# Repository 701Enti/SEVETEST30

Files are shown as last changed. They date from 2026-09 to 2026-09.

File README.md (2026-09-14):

# 简介

- 具有 16\*32RGB 显示阵列和大量环境传感器的物联网 AI 个性化时钟
- 基于 ESP32S3 模组和 ESP-IDF 框架开发
- 仅 TYPE-C 接入即可实现充电和程序调试(支持接口静电保护)
- 使用具有长边 32 灯\*短边 16 灯,共计 512 个 RGB灯珠的灯板 + 驱动板组成的显示模块
- 灯板和主控板采用易插拔的排线设计
- 板载电池和充电管理
- 支持电池电量计量
- 只需连接网络即可获取设备粗略位置并同步天气数据
- 最高支持 24bit 高保真音频播放/录制(DAC 最高支持 192kHz,ADC 最高支持 96kHz)
- 具有 3W 双声道音频功率放大器
- 喇叭接口采用易插拔端子设计
- 提供耳机输出
- 软件音量调节并支持蓝牙控制
- 环境光传感
- 板载麦克风阵列
- 姿态传感
- 地磁传感
- 线性振动马达
- 软关机低功耗设计
- NTP 网络时间同步
- TVOC 空气质量传感
- 温湿度传感
- 支持语音识别 ASR
- 支持语音合成 TTS
- 任意主流AI大语音模型API对话支持
- 通过物联工具实现个性化定制(等待开发和优化中)
- 交互式开关机(等待开发和优化中)

# 软件

- 业务代码编程语言为 C 语言
- 使用了 CMake 构建
- 基于 ESP-IDF 框架开发
- 本项目 IDE 开发环境推荐使用 Visual Studio Code / TRAE

# 软件安全设施

## .gitignore 敏感文件排除

- **SDK 配置文件 - sdkconfig**

  - SEVETEST30 的 WIFI 连接密码和 API 相关密钥均需要在 SDK 配置编辑器(menuconfig)设置,其生成的 sdkconfig 硬编码这些敏感内容
  - 提供安全的默认无密钥初始配置文件 sdkconfig.defaults

- **其他常见敏感文件**:
  - 环境变量和其他配置文件（含 API 密钥/数据库密码）
  - 加密密钥和证书文件（SSL/SSH 私钥）
  - 云服务凭证文件（AWS/GCP 访问密钥）
  - 数据库文件和备份（可能含敏感数据）
  - 日志文件（可能泄露调试信息）
  - 开发工具配置文件（含私有仓库令牌）
  - 网络连接配置文件（VPN/RDP 凭证）

## 关键分支的 PR 检查(基于 TruffleHog)

- **相关技术实现**:

  - 当 SEVETEST30 仓库的关键分支有新的 pull&request 时,必须经过 Github 工作流检查才可以进行 pull&request(需要仓库设置规则)
  - 工作流中使用 TruffleHog 检查整个提交历史是否含敏感内容
  - 也可以手动触发来人工检查结果

- **相关工作流**:
  - .github/workflows/TruffleHogPRCheck.yml

# 硬件

- **控制板 - SEVETEST30 核心控制板(50mm \* 100mm)**:

  - (目前硬件调试中,以下芯片使用仅供参考,很可能随时终止或更换某些器件的使用,请勿用于现实业务,修改恕不通知,建议等待正式版发布)[^4]
  - (由于硬件更改的可能,硬件工程文件尚不公开分发,我们可能在正式版发布时正式发布相关硬件文件)
  - MCU 模组:ESP32-S3-WROOM-1(N16R8 版本)
  - 字库:GT32L32S0140
  - 音频编解码:ES8388
  - 音频功率放大器:NS4268
  - 数字电位器(音量调节):TPL0401B
  - IO 扩展器:TCA6416A
  - 环境光传感器:OPT3001
  - 麦克风阵列:ZTS6156
  - 姿态传感器:LSM6DS3TRC
  - 地磁传感器:HSCDTD008A
  - 线性振动马达
  - 线性振动马达驱动器:BD6210F-E2
  - 离线 RTC:BL5372
  - TVOC 空气质量传感器:AGS10
  - 温湿度传感器:AHT21
  - DC-DC 电池充放电管理:SLM6300
  - 电池电量计量:MAX17048G+T10
  - USB 接口保护:UBT26A05L03
  - 电池(3.7V) -> 辅助电源(5V) DC-DC 升压芯片:TPS61230ARNSR
  - 数字电位器(辅助电源电压下调):TPL0401A
  - 辅助电源(5V) -> 主电源(3.3V) LDO 降压芯片:CJT1117B-3.3
  - 主电源(3.3V) -> AGS10 供电(3v) LDO 降压芯片:H7130-1

- **显示板 - SEVETEST30 灯板(50mm \* 100mm)**:

  - 普通共阳RGB灯珠

- **显示驱动板 - SEVETEST30 显示驱动板(50mm \* 100mm)**:

  - ICND2013
  - ICND2038S

- **必要设备 I2C 硬件通信地址**:

  - ES8388 (音频编解码) - 10
  - TPL0401B(音量调整) - 3E
  - TPL0401A(5V 电压下调) - 2E
  - TCA6416A(IO 扩展) - 20
  - MAX17048(电量计量) - 36

- **自举设备 I2C 硬件通信地址**:

  - AHT21(温湿度传感) - 38
  - AGS10(空气质量传感) - 1A
  - OPT3001(环境光传感) - 44
  - LSM6DS3TR-C(姿态传感) - 6A
  - HSCDTD008A(地磁传感) - 0C

# 硬件安全设施

## 接口保护

- **USB 接口**:
  - 支持静电保护,通过 UBT26A05L03
  - 支持浪涌保护,通过 UBT26A05L03

# 文档相关

## 在 Github 上的 SEVETEST30 文档仓库

- **仓库链接**: https://github.com/701Enti/DOC-SEVETEST30
- **文档撰写方式**: Doxygen 根据代码和注释生成
- **特别声明**:
  - SEVETEST30 文档仓库不是私有仓库,您完全可以 push 个人分支生成的文档到独立分支,甚至可以是您对 SEVETEST30 的见解等其他任何与 SEVETEST30 相关的内容,只要您没有影响自动文档或进行不合理的推送
  - 为保证资源充足,只会为关键分支提供自动文档生成,具体会触发工作流的关键分支在工作流文件 DoxygenAutoDocSync.yml 中可设置和查看
  - 当然,如果您希望自己的分支像关键分支一样可云端部署文档,您可以在本地运行 Doxygen 生成文档,并推送到 SEVETEST30 文档仓库与个人分支同名的分支,之后可联系 SEVETEST30 团队协商,他们管理文档的云端部署
- **文档修改**:
  - 更改 SEVETEST30 仓库的源码和注释内容即可,因为生成就是根据这些完成的,代码即文档
  - 由于生成结果文件非常多,不适合编辑修改管理工作,并且生成后的推送会覆盖之前的所有内容,更改源码注释反而更可靠,因此,目前不考虑生成后文件内容再修改的工作,即使是发布分支
- **相关技术实现**:
  - 当 SEVETEST30 仓库的关键分支有新的 push/pull&request 时(或者手动触发),自动在 Github 工作流中使用 Doxygen 生成文档,并提交新文档到文档仓库的同名分支
  - 例如 SEVETEST30 名为 A 分支的推送,将触发文档仓库名为 A 分支的更新
  - 文档生成和推送工作使用可复用工作流: https://github.com/701Enti/Github-WorkFlows/blob/master/.github/workflows/doxygen-auto-code-to-doc.yml (它存储在 701Enti 的专门工作流文件存储库)
  - 为保证资源充足,只会为关键分支提供自动文档生成,具体会触发工作流的关键分支在工作流文件 DoxygenAutoDocSync.yml 中可设置和查看
- **全流程案例**:
  - 以下是通过 Doxygen 自动生成官方文档的相关工作全流程(仅针对关键分支,如分支 A)
  - SEVETEST30 仓库关键分支 A 的 push
  - -> DoxygenAutoDocSync 触发
  - -> DoxygenAutoDocSync 调用 doxygen-auto-code-to-doc
  - -> doxygen-auto-code-to-doc 触发,根据 A 分支代码生成文档并将更改推送到文档仓库的 A 分支
  - (doxygen-auto-code-to-doc 结束)
  - -> DoxygenAutoDocSync 调用 OfficialDocSubmoduleSync
  - -> OfficialDocSubmoduleSync 触发,更新子模块,将更改推送到 A 分支的机器人分支并发起该分支到 A 分支的 PR
  - (OfficialDocSubmoduleSync 结束)
  - (DoxygenAutoDocSync 结束)
  - -> PR 审查 -> 完成
  - [注意: SEVETEST30 仓库是将每个文档仓库作为子模块独立管理的,子模块名必须与文档仓库名一致]
- **相关工作流**:
  - .github/workflows/DoxygenAutoDocSync.yml
  - .github/workflows/OfficialDocSubmoduleSync.yml
  - https://github.com/701Enti/Github-WorkFlows/blob/master/.github/workflows/doxygen-auto-code-to-doc.yml

# 第三方代码使用声明

## components/matrix_f64/matrix_fp64_mult_ansi.c

- **原项目**: esp-dsp
- **项目链接**: https://github.com/espressif/esp-dsp
- **原文件**: dspm_mult_f32_ansi.c
- **原文件协议类型**: Apache License 2.0
- **原文件 LICENSE 链接**: http://www.apache.org/licenses/LICENSE-2.0
- **修改说明**:
  - 类型为 float 的输入/输出参数被修改为 double 类型以提高运算精度[^1]
  - 函数名中的"\_f32"被删除,"dspm"或"dsps"改为"matrix_fp64"
  - 文件重命名：dspm_mult_f32_ansi.c → matrix_fp64_mult_ansi.c
  - 注释了原文件所有包含,仅包含接口头文件 matrix_fp64.h

## components/matrix_f64/matrix_fp64_sub_ansi.c

- **原项目**: esp-dsp
- **项目链接**: https://github.com/espressif/esp-dsp
- **原文件**: dsps_sub_f32_ansi.c
- **原文件协议类型**: Apache License 2.0
- **原文件 LICENSE 链接**: http://www.apache.org/licenses/LICENSE-2.0
- **修改说明**:
  - 类型为 float 的输入/输出参数被修改为 double 类型以提高运算精度[^1]
  - 函数名中的"\_f32"被删除,"dspm"或"dsps"改为"matrix_fp64"
  - 文件重命名：dsps_sub_f32_ansi.c → matrix_fp64_sub_ansi.c
  - 添加接口头文件 matrix_fp64.h 的包含

## components/matrix_f64/matrix_fp64_dotprod_ansi.c

- **原项目**: esp-dsp
- **项目链接**: https://github.com/espressif/esp-dsp
- **原文件**: dsps_dotprod_f32_ansi.c
- **原文件协议类型**: Apache License 2.0
- **原文件 LICENSE 链接**: http://www.apache.org/licenses/LICENSE-2.0
- **修改说明**:
  - 类型为 float 的输入/输出参数被修改为 double 类型以提高运算精度[^1]
  - 函数名中的"\_f32"被删除,"dspm"或"dsps"改为"matrix_fp64"
  - 文件重命名：dspm_sub_f32_ansi.c → matrix_fp64_dotprod_ansi.c
  - 注释了原文件所有包含,仅包含接口头文件 matrix_fp64.h

## sevetest30_board/board_def.h

- **原项目**: esp-adf
- **项目链接**: https://github.com/espressif/esp-adf
- **项目 LICENSE 链接**: https://github.com/espressif/esp-adf/blob/master/LICENSE
- **原文件**: board_def.h
- **原文件协议类型**: MIT
- **修改说明**:
  - 更改为项目需要的数值设置
  - 添加一些项目个性化需要的定义

## sevetest30_board/board_pins_config.c

- **原项目**: esp-adf
- **项目链接**: https://github.com/espressif/esp-adf
- **项目 LICENSE 链接**: https://github.com/espressif/esp-adf/blob/master/LICENSE
- **原文件**: board_pins_config.c
- **原文件协议类型**: MIT
- **修改说明**:
  - 更改为项目需要的数值设置

## sevetest30_board/board_pins_config.h

- **原项目**: esp-adf
- **项目链接**: https://github.com/espressif/esp-adf
- **项目 LICENSE 链接**: https://github.com/espressif/esp-adf/blob/master/LICENSE
- **原文件**: board_pins_config.h
- **原文件协议类型**: MIT
- **修改说明**:
  - 更改为项目需要的数值设置

## sevetest30_board/board.c

- **原项目**: esp-adf
- **项目链接**: https://github.com/espressif/esp-adf
- **项目 LICENSE 链接**: https://github.com/espressif/esp-adf/blob/master/LICENSE
- **原文件**: board.c
- **原文件协议类型**: MIT
- **修改说明**:
  - 更改为项目需要的数值设置

## sevetest30_board/board.h

- **原项目**: esp-adf
- **项目链接**: https://github.com/espressif/esp-adf
- **项目 LICENSE 链接**: https://github.com/espressif/esp-adf/blob/master/LICENSE
- **原文件**: board.h
- **原文件协议类型**: MIT
- **修改说明**:
  - 更改为项目需要的数值设置

## main/AGS10.c 和 main/include/AGS10.h 的 Calc_CRC8 函数

- **原文件**:来自奥松电子官方的 AGS10 数据手册内(需登录后点击"文件下载"获取手册) https://www.aosong.com/Products/info.aspx?lcid=&proid=49
- **原文件协议类型**: (未发现声明)
- **修改说明**:
  - 添加日志打印相关

## [^1]: 值得明确的是修改为 double 后,运算需要的时间可能延长

## [^4]: 本项目开发者和贡献者不承担任何硬件更改活动导致的财产损失,信息泄露和人员伤亡(详见下方 法律声明 - 免责声明)

# 法律声明 - 版权相关

1. 所有文件头部均已保留原始版权声明
2. 完整协议文本请通过附加的相关链接查看
3. 详细修改记录见各文件头部注释块
4. 为了明确第三方代码的原作者信息,相关内容及 API 帮助不在 SEVETEST30 文档中显示

# 法律声明 - 免责声明

- 本项目的开发者及贡献者（以下简称“我们”）不对任何因使用本项目（包括但不限于硬件修改、软件配置或数据使用）导致的直接或间接损失负责，包括但不限于：
- 硬件损坏、财产损失或人身伤害；
- 数据泄露、隐私问题或系统故障；
- 因违反法律法规或第三方权利导致的后果。
- 使用本项目即代表您同意自行承担所有风险。我们不提供任何明示或默示的担保，包括适销性、特定用途适用性或无侵权保证。
- 如需正式法律条款，请参阅项目许可证（LICENSE 文件）或单独的法律文件。

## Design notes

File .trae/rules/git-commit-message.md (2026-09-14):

---
alwaysApply: true
scene: git_message
---

在此处编写规则，自定义 AI 生成提交信息的风格。
中文提交信息

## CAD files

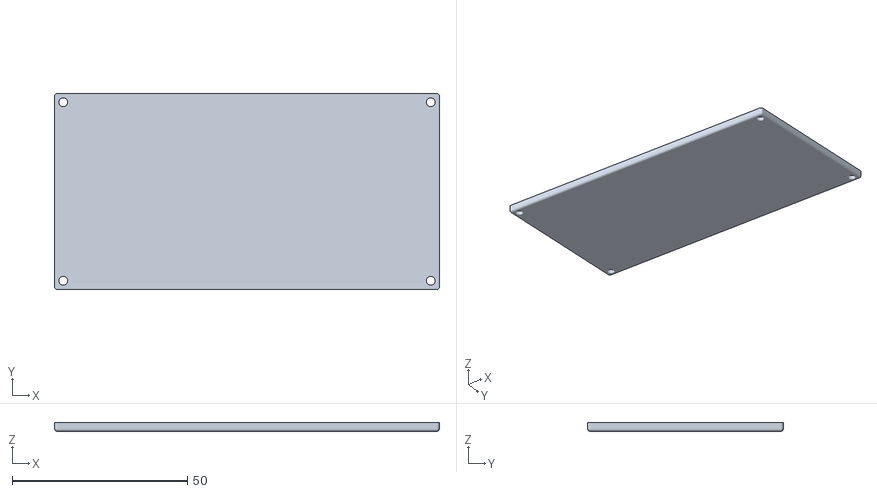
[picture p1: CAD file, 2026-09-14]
cad_case/export/stl/盖板.stl
110.0 x 56.0 x 2.50

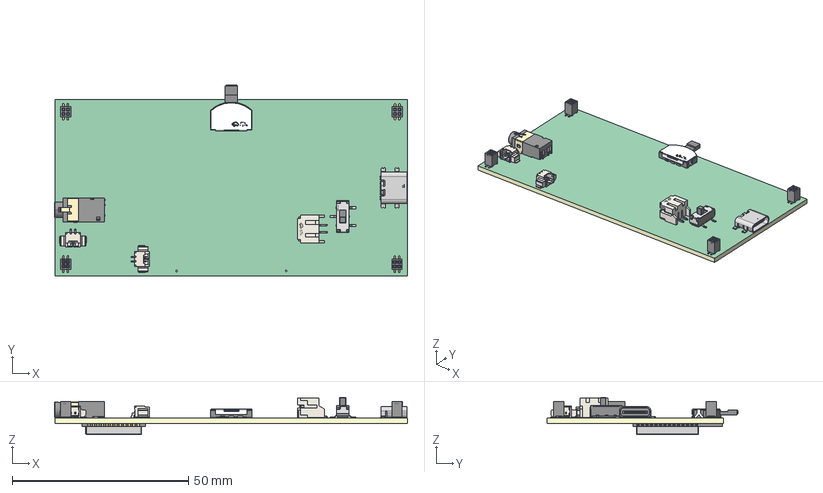
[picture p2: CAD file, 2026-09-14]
pcb/export/PT5/核心控制模块PT5_2026-08-22.step
100.1 x 54.1 x 10.5 mm
Board~6ucR
TopCopper~6ucR
BottomCopper~6ucR
TopSilkscreen~6ucR
BottomSilkscreen~6ucR
TopFpcStiffener~6ucR
BottomFpcStiffener~6ucR
HDR-SMD_ZX-PM1.27-2-2PU-W~HDR-SMD_ZX-PM1.27-2-2PU-W~6ucR x 4
CONN-SMD_2P-P2.00_XUNPU_WAFER-PH2.0-2PWB~CONN-SMD_2P-P2.00_XUNPU_ WAFER-PH2.0-2PWB~6ucR
CONN-SMD_532610271~CONN-SMD_532610271~6ucR x 2
SW-SMD_SHOUHAN_MST-22D18G23J_C2875122~SW-SMD_SHOUHAN_MST-22D18G23J_ C2875122~6ucR
USB-C-SMD_TYPEC-16PIN~USB-C-SMD_TYPEC-16PIN~6ucR
AUDIO-TH_ST-0337D00-071-1A2H~AUDIO-TH_ST-0337D00-071-1A2H~6ucR
SW-SMD_TM-2022-3~SW-SMD_TM-2022-3~6ucR
WIRELM-SMD_ESP32-S3-WROOM-1~WIRELM-SMD_ESP32-S3-WROOM-1~6ucR

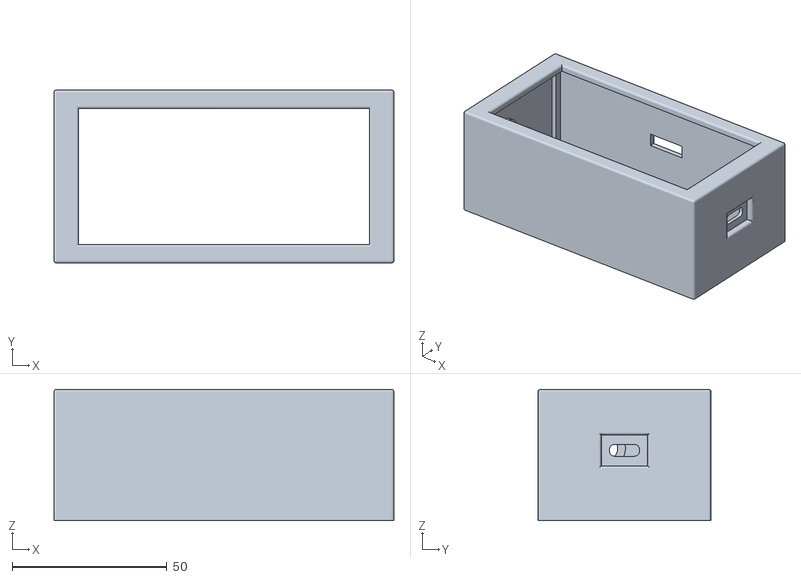
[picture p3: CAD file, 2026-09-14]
cad_case/export/stl/壳体.stl
110.0 x 56.0 x 42.5

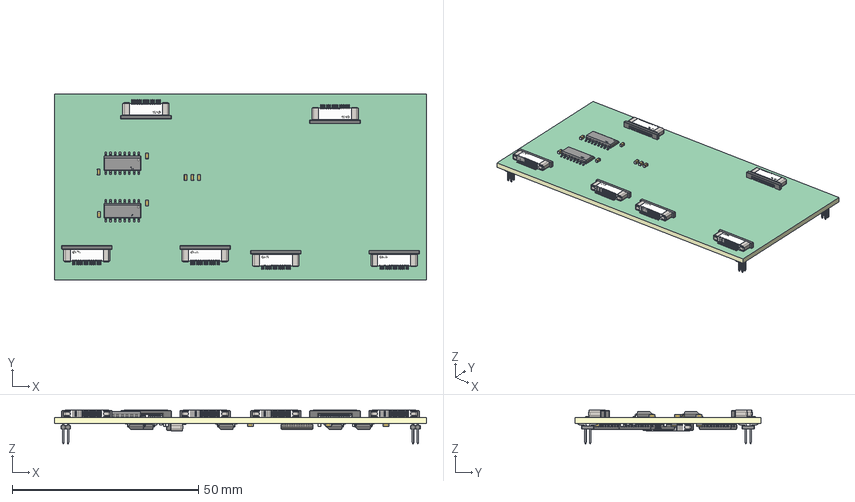
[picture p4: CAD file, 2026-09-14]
pcb/export/PT5/显示驱动模块_2026-08-22.step
100.0 x 50.0 x 9.10 mm
Board~aeRw
TopCopper~aeRw
BottomCopper~aeRw
TopSilkscreen~aeRw
BottomSilkscreen~aeRw
TopFpcStiffener~aeRw
BottomFpcStiffener~aeRw
HDR-SMD_4P-P1.27-V-M-R2-C2-LS5.3~HDR-SMD_4P-P1.27-V-M-R2-C2-LS5.3~aeRw x 4
R0603~R0603~aeRw x 12
C0603~C0603_L1.6-W0.8-H0.8~aeRw x 14
SOP-16_L9.9-W3.9-P1.27-LS6.0-BL~SOP-16_L9.9-W3.9-P1.27-LS6.0-BL~aeRw x 2
SSOP-24_L8.7-W3.9-P0.64-LS6.0-BL_1~SSOP-24_ L8.7-W3.9-P0.64-LS6.0-BL~aeRw x 6
FPC-SMD_P0.50-16P_LCS-SJ-H2.0~FPC-SMD_P0.50-16P_LCS-SJ-H2.0~aeRw x 7

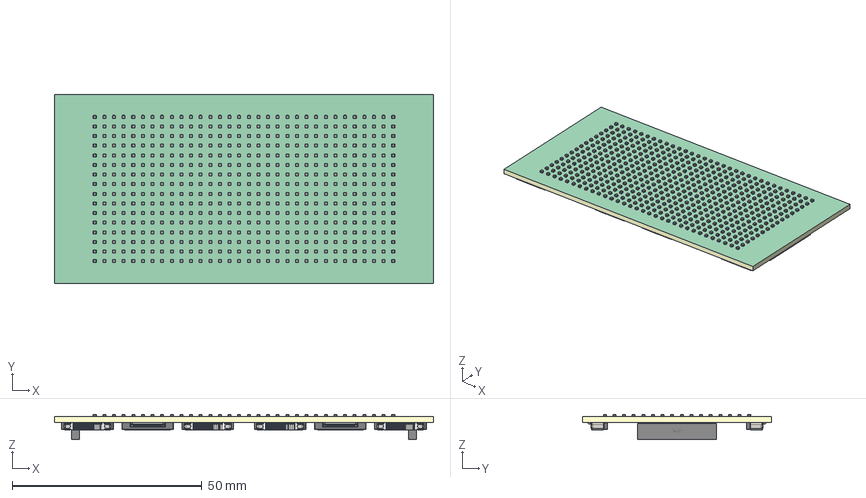
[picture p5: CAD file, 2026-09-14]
pcb/export/PT5/显示面板_2026-08-22.step
100.0 x 50.0 x 6.69 mm
Board~eJlu
TopCopper~eJlu
BottomCopper~eJlu
TopSilkscreen~eJlu
BottomSilkscreen~eJlu
TopFpcStiffener~eJlu
BottomFpcStiffener~eJlu
LED-ARRAY-SMD_4P-L0.80-W0.80-BR~LED-ARRAY-SMD_ 4P-L0.80-W0.80-H0.6-BR~eJlu x 512
FPC-SMD_P0.50-16P_LCS-SJ-H2.0~FPC-SMD_P0.50-16P_LCS-SJ-H2.0~eJlu x 6
HDR-SMD_16P-P1.27-V-F_X1311FVS-16-C43D35R2~HDR-SMD_16P-P1.27-V-F_ X1311FVS-16-C43D35R2~eJlu x 2

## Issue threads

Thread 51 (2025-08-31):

传感器校准generate_GS_calibration_static_model工作流程潜在问题修复

Zeng-Jinlin, 2025-08-31:
修复generate_GS_calibration_static_model工作流程潜在问题,可能保护数学库完善和修复:
我们使用椭球拟合算法完成对校准模型的构建
由于各种因素,传感器测得数据点分布近似一个x-y-z空间中的椭球
算出这个椭球相关参数,确定它,我们就可反过来推算实际值
然而,出现计算结果不合理,如参数小于0问题,这不正常,它不是椭球,因此我们需要修复bug

Zeng-Jinlin, 2025-08-31:
LU分解求逆是最小二乘法椭球拟合中关键一步,对于我们当前的方案选择来说

Zeng-Jinlin, 2025-08-31:
我们已经进行很多修复,并同时增加优化

Zeng-Jinlin, 2025-08-31:
但是实际校准工作测试发现椭球拟合结果还是存在负值,问题依旧
这使我开始怀疑硬件问题,尤其是当初不懂,layout时,把传感器设计在PCB中间位置
我会网购一个HSCDTD008A小板,外接到我们的主控板,以验证这个猜想

Closed 2025-10-01.

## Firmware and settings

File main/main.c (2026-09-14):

/*
 * 701Enti MIT License
 *
 * Copyright © 2024 <701Enti organization>
 *
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
 * THE SOFTWARE IS PROVIDED “AS IS”, WITHOUT WARRANTY OF ANY KIND, EXPRESS OR
 * IMPLIED, INCLUDING BUT NOT LIMITED TO THE WARRANTIES OF MERCHANTABILITY,
 * FITNESS FOR A PARTICULAR PURPOSE AND NONINFRINGEMENT. IN NO EVENT SHALL THE
 * AUTHORS OR COPYRIGHT HOLDERS BE LIABLE FOR ANY CLAIM, DAMAGES OR OTHER
 * LIABILITY, WHETHER IN AN ACTION OF CONTRACT, TORT OR OTHERWISE, ARISING FROM,
 * OUT OF OR IN CONNECTION WITH THE SOFTWARE OR THE USE OR OTHER DEALINGS IN THE
 * SOFTWARE.
 */

// 如您发现一些问题，请及时联系我们，我们非常感谢您的支持
// github: https://github.com/701Enti

#include <stdbool.h>
#include <stdint.h>
#include <stdio.h>
#include <string.h>

#include "esp_log.h"
#include "esp_peripherals.h"

#include "esp_sleep.h"
#include "esp_wifi.h"
#include "freertos/idf_additions.h"
#include "lwip/dns.h"
#include "nvs_flash.h"

#include "OPT3001.h"
#include "audio_hal.h"
#include "board_ctrl.h"
#include "board_def.h"
#include "board_pins_config.h"
#include "gt32l32s0140.h"

#include "HSCDTD008A.h"
#include "TCA6416A.h"
#include "calibration_tools.h"
#include "esp_timer.h"
#include "math_tools.h"
#include "sevetest30_BWEDA.h"
#include "sevetest30_IWEDA.h"
#include "sevetest30_LedArray.h"
#include "sevetest30_SWEDA.h"
#include "sevetest30_UI.h"
#include "sevetest30_config.h"
#include "sevetest30_gpio.h"
#include "sevetest30_sound.h"
#include "sevetest30_touch.h"

board_ctrl_t board_ctrl = {0};

char *system_json_head_prompt =
    "你是一个部署在SEVETEST30智能闹钟上的AI语音助手,"
    "你的名字是:07(零七,中文谐音寓意trying,数字取自701Enti),"
    "SEVETEST30是github上的701Enti组织归属的非盈利开源项目."
    "你可以和我聊天,简单的问题尽量用简短文字回答问题."
    "以下信息来自我的SEVETEST30闹钟通过网络API或硬件传感器获取的数据."
    "实时更新,我们的聊天可以不涉及."
    "注意:你需要根据时区获取当前时间,这里不会提供."
    "注意:位置数据来自IP定位,不要引起用户不必要的恐慌,经纬度数据可能不准确."
    "注意:用户通过语音识别聊天,文字书写可能错误,请重点关注拼音和上下文,"
    "忽略多音字歧义.";

void init(void);
void test(void);

esp_err_t AI_chat(void);

void app_main(void) {

  init();

  refresh_battery_data();
  refresh_env_temp_hum_data();
  refresh_env_TVOC_data(true);

  refresh_position_data();
  refresh_current_weather_data();

  if (xSemaphoreTake(update_ui_data_mutex, pdMS_TO_TICKS(100)) == pdTRUE) {
    clean_all_draw_buf();
    xSemaphoreGive(update_ui_data_mutex);
  }

  test();

  int UI_switch = 0;
  bool UI_changed = false;
  int64_t UI_changed_time = 0;

  while (1) {

    vTaskDelay(pdMS_TO_TICKS(10));

    refresh_systemtime_data();

    if (ext_io_ctrl.auto_read_INT) {
      if (ext_io_level_service() == ESP_OK) {
        ext_io_ctrl.auto_read_INT = false;

        if (board_ctrl.p_ext_io_value->thumbwheel_CW == 0 &&
            board_ctrl.p_ext_io_value->thumbwheel_CCW == 1) {
          if (board_ctrl.p_ext_io_value->DISABLE_LED_BOARD) {
            continue;
          }
          vibra_motor_start();
          vTaskDelay(pdMS_TO_TICKS(50));
          vibra_motor_stop();
          UI_switch++;
          UI_changed = true;
        } else if (board_ctrl.p_ext_io_value->thumbwheel_CW == 1 &&
                   board_ctrl.p_ext_io_value->thumbwheel_CCW == 0) {
          if (board_ctrl.p_ext_io_value->DISABLE_LED_BOARD) {
            continue;
          }
          vibra_motor_start();
          vTaskDelay(pdMS_TO_TICKS(50));
          vibra_motor_stop();
          UI_switch--;
          UI_changed = true;
        } else if (board_ctrl.p_ext_io_value->thumbwheel_CW == 0 &&
                   board_ctrl.p_ext_io_value->thumbwheel_CCW == 0) {

          vTaskDelay(pdMS_TO_TICKS(200));
          ext_io_level_service();

          if (!(board_ctrl.p_ext_io_value->thumbwheel_CW == 0 &&
                board_ctrl.p_ext_io_value->thumbwheel_CCW == 0)) {
            board_ctrl.p_ext_io_value->DISABLE_LED_BOARD =
                !(board_ctrl.p_ext_io_value->DISABLE_LED_BOARD);
            sevetest30_board_ctrl(&board_ctrl, BOARD_CTRL_EXT_IO);
            vibra_motor_start();
            vTaskDelay(pdMS_TO_TICKS(100));
            vibra_motor_stop();
            continue;
          }

          if (board_ctrl.p_ext_io_value->DISABLE_LED_BOARD) {
            continue;
          }

          if (xSemaphoreTake(update_ui_data_mutex, pdMS_TO_TICKS(100)) ==
              pdTRUE) {
            clean_all_draw_buf();
            facial_expression_show(1, 1, "normal");
            xSemaphoreGive(update_ui_data_mutex);
          }

          vibra_motor_start();
          vTaskDelay(pdMS_TO_TICKS(50));
          vibra_motor_stop();
          vTaskDelay(pdMS_TO_TICKS(100));
          vibra_motor_start();
          vTaskDelay(pdMS_TO_TICKS(50));
          vibra_motor_stop();

          int64_t start_time = esp_timer_get_time();
          while (board_ctrl.p_ext_io_value->thumbwheel_CW == 0 &&
                 board_ctrl.p_ext_io_value->thumbwheel_CCW == 0) {
            vTaskDelay(pdMS_TO_TICKS(100));
            ext_io_level_service();
            if (esp_timer_get_time() - start_time > 5 * 1000 * 1000) {
              vibra_motor_start();
              sevetest30_shutdown();
            }
          }

          esp_err_t ret = AI_chat();
          if (ret != ESP_OK) {
            ESP_LOGE("main", "AI_chat 失败,错误码：%d", ret);
            if (xSemaphoreTake(update_ui_data_mutex, pdMS_TO_TICKS(100)) ==
                pdTRUE) {
              clean_all_draw_buf();
              if (ret == ESP_ERR_INVALID_STATE) {
                show_wifi_not_connected(1, 1);
              } else if (ret == ESP_FAIL) {
                facial_expression_show(1, 1, "error");
              }
              xSemaphoreGive(update_ui_data_mutex);
              vTaskDelay(pdMS_TO_TICKS(1000));
            }
          }
          UI_changed = true;
        }
      }
    }

    if (xSemaphoreTake(update_ui_data_mutex, 100) == pdTRUE) {
      switch (UI_switch) {
      case -1: {
        if (UI_changed) {
          clean_all_draw_buf();
          memset(media_ctrl_roll_print_str, 0,
                 sizeof(media_ctrl_roll_print_str));
        }
        if (xSemaphoreTake(data_mutex_media_ctrl_roll_print, 100) == pdTRUE) {
          if (media_ctrl_roll_print_str[0] != 0) {
            uint8_t color[3] = {255, 255, 255};
            clean_all_draw_buf();
            ESP_LOGI("main", "滚动打印：%s", media_ctrl_roll_print_str);
            font_roll_print_16x(1, 1, color, NULL, "%s",
                                media_ctrl_roll_print_str);
            memset(media_ctrl_roll_print_str, 0,
                   sizeof(media_ctrl_roll_print_str));
            clean_all_draw_buf();
          }
          xSemaphoreGive(data_mutex_media_ctrl_roll_print);
        }
      } break;
      case 0:
        clean_all_draw_buf();
        time_UI_h_m_s(1, 1);
        break;
      case 1:
        clean_all_draw_buf();
        weather_icon_temperature(1, 1);
        break;
      case 2:
        clean_all_draw_buf();
        if (UI_changed) {
          refresh_battery_data();
        }
        battery_UI(1, 1);
        if (board_ctrl.p_ext_io_value->charge_SIGN == 0) {
          static int i = 0;
          static uint8_t rectangle_data[VERTICAL_LED_NUMBER * sizeof(uint8_t) +
                                        sizeof(uint32_t)];
          uint8_t color[3] = {255, 255, 255};

          build_rectangle(1, i / 100.0f * (int)(VERTICAL_LED_NUMBER / 2),
                          rectangle_data, sizeof(rectangle_data));
          separation_draw(LINE_LED_NUMBER, (VERTICAL_LED_NUMBER / 2), 1,
                          RECTANGLE_MATRIX(rectangle_data),
                          matrix_size(rectangle_data), color, false);
          i++;
          if (i > 100) {
            i = 0;
          }
        }
        break;
      case 3:
        clean_all_draw_buf();
        time_UI_h_m(1, 1);
        break;
      case 4:
        clean_all_draw_buf();
        time_UI_s(1, 1);
        break;
      default:
        UI_switch = 0;
        break;
      }
      xSemaphoreGive(update_ui_data_mutex);

      if (UI_changed) {
        UI_changed_time = esp_timer_get_time();
        UI_changed = false;
      } else {
        if (UI_switch != 0 && UI_switch > 0) {
          if (esp_timer_get_time() - UI_changed_time > 15 * 1000 * 1000) {
            UI_switch = 0;
          }
        }
      }
    }
  }

  return;
}

void init(void) {
  const char *TAG = "init";

  static TCA6416A_mode_t ext_io_mode_data = TCA6416A_DEFAULT_CONFIG_MODE;
  static TCA6416A_level_t ext_io_value_data = TCA6416A_DEFAULT_CONFIG_VALUE;

  board_ctrl.p_ext_io_mode = &ext_io_mode_data;
  board_ctrl.p_ext_io_value = &ext_io_value_data;
  board_ctrl.amplifier_volume = 60;
  board_ctrl.amplifier_mute = true;
  board_ctrl.amplifier_sd = false;
  board_ctrl.codec_audio_hal_ctrl = AUDIO_HAL_CTRL_START;
  board_ctrl.codec_mode = AUDIO_HAL_CODEC_MODE_BOTH;
  board_ctrl.codec_adc_gain = MIC_GAIN_15DB;
  board_ctrl.codec_dac_pin = DAC_OUTPUT_ALL;
  board_ctrl.codec_dac_volume = 100;
  board_ctrl.codec_adc_pin = CODEC_ADC_INPUT_MIC_ON_BOARD;

  sevetest30_all_device_init(&board_ctrl);

  // 打开屏幕显示
  board_ctrl_t *b = board_status_get();
  b->p_ext_io_value->DISABLE_LED_BOARD = 0;
  sevetest30_board_ctrl(b, BOARD_CTRL_EXT_IO);

  ext_io_ctrl.auto_read_EN = true;
  ext_io_level_service();
  refresh_battery_data();

  // 如果当前不在充电，非长按/连续快速按下拨轮开关禁止开机
  // （设置“当前不在充电“条件主要为了防止连接电脑时的调试不便，但是如果连接电脑时电池充满也是不在充电，这是潜在缺陷）
  // （如果调试时发现不能启动，请注释该代码块，或者烧写代码后手动开机）
  if (board_ctrl.p_ext_io_value->charge_SIGN == 1) {
    if (!(board_ctrl.p_ext_io_value->thumbwheel_CW == 0 &&
          board_ctrl.p_ext_io_value->thumbwheel_CCW == 0)) {
      sevetest30_shutdown();
    }
    ext_io_level_service();
    vTaskDelay(pdMS_TO_TICKS(1000));
    if (!(board_ctrl.p_ext_io_value->thumbwheel_CW == 0 &&
          board_ctrl.p_ext_io_value->thumbwheel_CCW == 0)) {
      sevetest30_shutdown();
    }
    vibra_motor_start();
    vTaskDelay(pdMS_TO_TICKS(1000));
    vibra_motor_stop();
  }

  // 电量低且未在充电禁止开机
  if (battery_data.result.battery_soc < 10 &&
      board_ctrl.p_ext_io_value->charge_SIGN == 1) {
    battery_UI(1, 1);
    vTaskDelay(pdMS_TO_TICKS(5000));
    sevetest30_shutdown();
  }

  show_701Enti_sign(1, 1);

  // 初始化NVS存储
  esp_err_t ret = nvs_flash_init();
  if (ret == ESP_ERR_NVS_NO_FREE_PAGES ||
      ret == ESP_ERR_NVS_NEW_VERSION_FOUND) {
    ESP_ERROR_CHECK(nvs_flash_erase());
    ret = nvs_flash_init();
  }
  ESP_ERROR_CHECK(ret);

  start_bluetooth_connect_service();

  esp_periph_config_t wifi_periph_config = DEFAULT_ESP_PERIPH_SET_CONFIG();
  wifi_init(&wifi_periph_config);
  // 载入wifi信息
  periph_wifi_cfg_t wifi_cfg = {
      .disable_auto_reconnect = false,
      .wifi_config.sta.ssid = CONFIG_WIFI_SSID,
      .wifi_config.sta.password = CONFIG_WIFI_PASSWORD,
  };
  if (wifi_connect(&wifi_cfg) != ESP_OK) {
    ESP_LOGE(TAG, "网络连接失败");
  } else {
    ESP_LOGI(TAG, "已连接到网络 - %s", wifi_cfg.wifi_config.sta.ssid);
    // // 关闭wifi省电模式
    // esp_wifi_set_ps(WIFI_PS_NONE);
    // 配置DNS服务器
    ip_addr_t dns_server;
    ipaddr_aton(CONFIG_DNS_SERVER, &dns_server);
    dns_setserver(0, &dns_server);
  }

  init_timezone();
  init_time_data_sntp(20000);

  show_se30_sign(1, 1);
}

void test(void) {
  // // 基础屏幕测试,仅测试能否显示变化矩形(启动自动刷新服务后,无需手动刷新)
  // uint8_t color[3] = {255,0,0};
  // while (1)
  // {
  //     vTaskDelay(pdMS_TO_TICKS(1000));
  //     for (int i = 0; i <= LINE_LED_NUMBER; i++)
  //     {
  //         clean_all_draw_buf();
  //         uint8_t *rp1 = rectangle(i, i);
  //         if (rp1 != NULL)
  //         {
  //             separation_draw(1, 1, i, RECTANGLE_MATRIX(rp1),
  //             matrix_size(rp1), color, true); free(rp1);
  //         }
  //         vTaskDelay(pdMS_TO_TICKS(500));
  //     }
  //     vTaskDelay(pdMS_TO_TICKS(1000));
  //     for (int i = LINE_LED_NUMBER; i >= 0; i--)
  //     {
  //         clean_all_draw_buf();
  //         uint8_t *rp1 = rectangle(i, i);
  //         if (rp1 != NULL)
  //         {
  //             separation_draw(1, 1, i, RECTANGLE_MATRIX(rp1),
  //             matrix_size(rp1), color, true); free(rp1);
  //         }
  //         vTaskDelay(pdMS_TO_TICKS(500));
  //     }
  // }

  // /// 滚动显示 屏幕动画测试+字库测试+UI库动画API测试
  // /// 其他参数渲染与多关键帧支持待完善,隐写关键帧正在测试阶段
  // uint8_t color[3] = {255, 255, 0};
  // while (1) {
  //   cartoon_handle_t cartoon1 =
  //       cartoon_new(CARTOON_RUN_MODE_PRE_RENDER, true, false, false, 10);
  //   if (cartoon1) {
  //     add_new_key_frame(cartoon1, KEY_FRAME_ATTR_LINEAR,
  //                       CARTOON_KEY_FRAME_PCT_MAX * 0, false, 1, 1, color);
  //     add_new_key_frame(cartoon1, KEY_FRAME_ATTR_LINEAR,
  //                       (float)CARTOON_KEY_FRAME_PCT_MAX * 0.5, false, -100,
  //                       1, color);
  //     uint32_t c1steg1 =
  //         add_new_key_frame(cartoon1, KEY_FRAME_ATTR_LINEAR,
  //                           CARTOON_KEY_FRAME_PCT_MAX * 1, false, 1, 1,
  //                           color);
  //     add_new_key_frame(cartoon1, KEY_FRAME_ATTR_STEGANOGRAPHY,
  //                       STEGANOGRAPHY_MODE_MAPPING_SUBTRACTION, c1steg1,
  //                       (int32_t)&cartoon1->cartoon_plan.total_step_buf,
  //                       (int32_t)NULL, NULL);

  //     font_roll_print_16x(1, 1, color, cartoon1,
  //     "hi,701Enti,美好皆于不懈尝试之中,热爱终在不断追逐之下,trying"
  //     "entire,trying all time!");

  //     cartoon_delete(cartoon1);
  //   }
  // }

  // // 实时时间显示
  // while (1)
  // {
  //   refresh_systemtime_data();
  //   if (xSemaphoreTake(update_ui_data_mutex, pdMS_TO_TICKS(100)) ==
  //   pdTRUE)
  //   {
  //     clean_all_draw_buf();
  //     time_UI_h_m_s(1, 1);
  //     xSemaphoreGive(update_ui_data_mutex);
  //   }
  //   vTaskDelay(pdMS_TO_TICKS(1000));
  // }

  // /// 歌词获取
  // char lrc[5000] = {0};
  // fetch_music_lyric_by_url("",lrc,5000);
  // ESP_LOGE("main", "%s",lrc);

  // // LSM6DS3TRC全部使用例子
  // //  (输出XYZ分量总是一致，待优化)FIFO
  // while (1)
  // {
  //   refresh_IMU_FIFO_data(NULL, 0, 0);
  //   for (int i = 0; i < 3; i++)
  //   {
  //     if ((IMU_XLx_L[i] | IMU_XLx_H[i] << 8) < 0x7FF0){
  //       ESP_LOGI("main", "X轴加速度:%d", (int16_t)(IMU_XLx_L[i] |
  //       IMU_XLx_H[i] << 8));
  //     }
  //     else{
  //       ESP_LOGI("main", "X轴加速度:---");
  //     }

  //     if ((IMU_XLy_L[i] | IMU_XLy_H[i] << 8) < 0x7FF0){
  //       ESP_LOGI("main", "Y轴加速度:%d", (int16_t)(IMU_XLy_L[i] |
  //       IMU_XLy_H[i] << 8));
  //     }
  //     else{
  //       ESP_LOGI("main", "Y轴加速度:---");
  //     }

  //     if ((IMU_XLz_L[i] | IMU_XLz_H[i] << 8) < 0x7FF0){
  //       ESP_LOGI("main", "Z轴加速度:%d", (int16_t)(IMU_XLz_L[i] |
  //       IMU_XLz_H[i] << 8));
  //     }
  //     else{
  //       ESP_LOGI("main", "Z轴加速度:---");
  //     }
  //   }
  //   vTaskDelay(pdMS_TO_TICKS(500));
  // }
  // // 姿态数据
  // while (1)
  // {
  //   vTaskDelay(pdMS_TO_TICKS(500));
  //   ESP_LOGI("main", "---------------------------");

  //   IMU_acceleration_value_t acceleration =
  //   LSM6DS3TRC_gat_now_acceleration(); ESP_LOGI("main", "加速度 X:%d Y:%d
  //   Z:%d", acceleration.x, acceleration.y, acceleration.z);

  //   IMU_angular_rate_value_t angular_rate =
  //   LSM6DS3TRC_gat_now_angular_rate(); ESP_LOGI("main", "角速度 X:%d Y:%d
  //   Z:%d", angular_rate.x, angular_rate.y, angular_rate.z);
  // }
  // // (偏移标志位不会自动设置为0，待优化)自动记录
  // while (1)
  // {
  //   vTaskDelay(pdMS_TO_TICKS(1000));
  //   IMU_D6D_data_value_t value = LSM6DS3TRC_get_D6D_data_value(true);
  //   ESP_LOGI("main", "D6D反向偏移标识 [%d<-X轴->%d] [%d<-Y轴->%d]
  //   [%d<-Z轴->%d]", value.XL, value.XH, value.YL, value.YH, value.ZL,
  //   value.ZH); ESP_LOGI("main", "温度 %.3f ℃",
  //   (double)LSM6DS3TRC_get_now_temperature() / 1000); if
  //   (LSM6DS3TRC_get_free_fall_status())
  //     ESP_LOGW("main", "自由落体");
  // }

  // //(经常出现校准失败，待优化) HSCDTD008A

  // HSCDTD008A_mode_set(GS_MODE_ACTIVE);
  // HSCDTD008A_state_set(GS_STATE_NORMAL);

  // ESP_LOGI("main", "5s后开始校准");
  // vTaskDelay(pdMS_TO_TICKS(5000));

  // GS_calibration_static_model_t static_model;
  // esp_err_t ret = generate_GS_calibration_static_model(&static_model, 200,
  // 100);

  // if (ret == ESP_OK) {
  //   GS_output_data_t output;
  //   GS_magnetic_flux_density_data_t mfd;
  //   GS_angle_data_t angle;
  //   while (1)
  //   {
  //     HSCDTD008A_output_data_get(&output);
  //     to_magnetic_flux_density_data(&output, &mfd);
  //     calculate_calibrated_GS_only_by_static_model(&static_model, &mfd);
  //     to_angle_data(GS_UNIT_OF_ANGLE_DEGREES, &mfd, &angle);
  //     ESP_LOGI("main", "方位---[%f]--- 俯仰|%f|", angle.azimuth,
  //     angle.pitch); ESP_LOGI("main", "x-[%f] y-[%f] z-[%f]", mfd.Bx, mfd.By,
  //     mfd.Bz); vTaskDelay(pdMS_TO_TICKS(1000));
  //   }
  // }

  // // 通过AHT21获取环境温度和湿度数据
  // refresh_env_temp_hum_data(true);
  // if (env_temp_hum_data.valid)
  // {
  //   ESP_LOGI("main", "环境温度:%.2f ℃, 环境湿度:%.2f%%",
  //   env_temp_hum_data.temp, env_temp_hum_data.hum);
  // }
  // else
  // {
  //   ESP_LOGE("main", "环境温度或湿度数据无效");
  // }

  // // 通过AGS10获取环境TVOC数据
  // ESP_LOGW("main", "等待预热中(每次完全掉电后上电需要预热,预计两分钟)...");
  // vTaskDelay(pdMS_TO_TICKS(120000));
  // while (1)
  // {
  //   vTaskDelay(pdMS_TO_TICKS(1000));
  //   refresh_env_TVOC_data(true);
  //   if (env_TVOC_data.valid)
  //   {
  //     ESP_LOGI("main", "环境TVOC:%" PRIu32 "ppb", env_TVOC_data.TVOC_value);
  //   }
  //   else
  //   {
  //     ESP_LOGE("main", "环境TVOC数据无效");
  //   }
  // }

  // // 通过OPT3001获取环境光照数据
  // while (1) {
  //   vTaskDelay(pdMS_TO_TICKS(1000));
  //   refresh_env_lux_data();
  //   if (env_lux_data >= 0.0f) {
  //     ESP_LOGI("main", "环境光照:%.2f lx", env_lux_data);
  //   } else {
  //     ESP_LOGE("main", "环境光照数据无效");
  //   }
  // }

  // // 通过MAX17048获取电池数据
  // while (1) {
  //   vTaskDelay(pdMS_TO_TICKS(1000));
  //   refresh_battery_data();
  //   if (battery_data.charge_flag) {
  //     ESP_LOGI("main", "电池充电中");
  //   } else {
  //     ESP_LOGI("main", "电池不处于充电状态");
  //   }
  //   if (battery_data.result.battery_voltage >= 0.0f) {
  //     ESP_LOGI("main", "电池电压:%.2fmV",
  //     battery_data.result.battery_voltage);
  //   } else {
  //     ESP_LOGE("main", "电池数据无效");
  //   }
  //   if (battery_data.result.battery_soc >= 0.0f) {
  //     ESP_LOGI("main", "电池SOC:%.2f%%", battery_data.result.battery_soc);
  //   } else {
  //     ESP_LOGE("main", "电池数据无效");
  //   }
  // }

  // music_FFT_UI_cfg_t FFT_UI_cfg = FFT_UI_DEFAULT_CONFIG();

  // // 网络音乐播放
  // // // espressif官方测试音频
  // // "https://dl.espressif.cn/dl/audio/ff-16b-2c-44100hz.mp3";
  // char *url1 ="https://dl.espressif.cn/dl/audio/ff-16b-2c-44100hz.mp3";

  // IWEDA_handle_t music_play_IWEDA_handle = new_iweda_handle(2048, 2048);
  // if (!music_play_IWEDA_handle) {
  //   ESP_LOGE("main", "music_play_IWEDA_handle 为空,无法绘制任务");
  //   return;
  // }

  // int url_len = snprintf(music_play_IWEDA_handle->url_buf,
  //                        music_play_IWEDA_handle->url_buf_size, "%s", url1);
  // if (url_len >= music_play_IWEDA_handle->url_buf_size) {
  //   ESP_LOGE("main", "url_len 超出 url_buf_size");
  //   return;
  // }
  // iweda_change_url_if_need_redirect(music_play_IWEDA_handle);

  // // 检查资源可用性
  // if (iweda_check_common_url(music_play_IWEDA_handle) == ESP_OK) {

  //   board_ctrl_t *b = board_status_get();
  //   b->amplifier_mute = false;
  //   b->amplifier_sd = true;
  //   b->amplifier_volume = 60;
  //   sevetest30_board_ctrl(b, BOARD_CTRL_AMPLIFIER);

  //   music_uri_or_url_play(music_play_IWEDA_handle->url_buf, 1);

  //   music_FFT_UI_handle_t handle = music_FFT_UI_start(&FFT_UI_cfg, 1);
  //   if (!handle) {
  //     ESP_LOGE("main", "handle 为空,无法绘制任务");
  //     return;
  //   }

  //   while (1) {
  //     if (handle &&
  //         xSemaphoreTake(update_ui_data_mutex, pdMS_TO_TICKS(10)) == pdTRUE)
  //         {
  //       clean_all_draw_buf();
  //       music_FFT_UI_draw(handle);
  //       xSemaphoreGive(update_ui_data_mutex);
  //     }
  //     vTaskDelay(pdMS_TO_TICKS(10));
  //     if (!sevetest30_music_running_flag) {
  //       music_FFT_UI_stop(handle);
  //       delete_iweda_handle(music_play_IWEDA_handle);
  //       music_play_IWEDA_handle = NULL;
  //       break;
  //     }
  //   }
  // }

  // // 震动马达-震动测试
  //    while(1){
  //    vibra_motor_start();
  //    vTaskDelay(pdMS_TO_TICKS(500));
  //    vibra_motor_stop();
  //    vTaskDelay(pdMS_TO_TICKS(500));
  //   }

  // // 震动马达-震动测试+实时时间显示，模拟闹钟响铃
  // while (1)
  // {
  //   refresh_systemtime_data();
  //   if (xSemaphoreTake(update_ui_data_mutex, pdMS_TO_TICKS(100)) ==
  //   pdTRUE)
  //   {
  //     clean_all_draw_buf();
  //     time_UI_h_m_s(1, 1);
  //     xSemaphoreGive(update_ui_data_mutex);
  //   }
  //   vibra_motor_start();
  //   vTaskDelay(pdMS_TO_TICKS(500));
  //   vibra_motor_stop();
  //   vTaskDelay(pdMS_TO_TICKS(500));
  // }

  // // // 震动马达-触感反馈测试
  // vTaskDelay(pdMS_TO_TICKS(1000));
  // ext_io_ctrl.auto_read_EN = true;
  // ext_io_ctrl.auto_read_INT = false;
  // while (1)
  // {
  //   if (ext_io_ctrl.auto_read_INT)
  //   {
  //     if (ext_io_level_service() == ESP_OK)
  //     {
  //       ext_io_ctrl.auto_read_INT = false;
  //       ESP_LOGW("main", "扩展GPIO自动读取中断触发成功");
  //       vibra_motor_start();
  //       vTaskDelay(pdMS_TO_TICKS(50));
  //       vibra_motor_stop();
  //     }
  //   }
  //   vTaskDelay(pdMS_TO_TICKS(100));
  // }

  // // 获取当前连接wifi的信号强度(RSSI)
  // wifi_ap_record_t ap_info;
  // if (esp_wifi_sta_get_ap_info(&ap_info) == ESP_OK)
  // {
  //   ESP_LOGW("main", "当前连接wifi的信号强度(RSSI): %d", ap_info.rssi);
  // }

  // // TTS在线文字转语音
  // board_ctrl_t *board_tts = board_status_get();
  // board_tts->amplifier_mute = false;
  // board_tts->amplifier_sd = true;
  // board_tts->amplifier_volume = 60;
  // sevetest30_board_ctrl(board_tts, BOARD_CTRL_AMPLIFIER);

  // TTS_cfg_t tts_cfg =
  // TTS_DEFAULT_CONFIG("你好，我是SEVETEST30，你可以和我聊天", 0);
  // tts_service_play_short(&tts_cfg, 1); // 启动TTS服务
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

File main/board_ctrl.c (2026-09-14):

/*
 * 701Enti MIT License
 *
 * Copyright © 2024 <701Enti organization>
 *
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
 * THE SOFTWARE IS PROVIDED “AS IS”, WITHOUT WARRANTY OF ANY KIND, EXPRESS OR
 * IMPLIED, INCLUDING BUT NOT LIMITED TO THE WARRANTIES OF MERCHANTABILITY,
 * FITNESS FOR A PARTICULAR PURPOSE AND NONINFRINGEMENT. IN NO EVENT SHALL THE
 * AUTHORS OR COPYRIGHT HOLDERS BE LIABLE FOR ANY CLAIM, DAMAGES OR OTHER
 * LIABILITY, WHETHER IN AN ACTION OF CONTRACT, TORT OR OTHERWISE, ARISING FROM,
 * OUT OF OR IN CONNECTION WITH THE SOFTWARE OR THE USE OR OTHER DEALINGS IN THE
 * SOFTWARE.
 */

// 包含各种SE30针对性硬件控制
// 如您发现一些问题，请及时联系我们，我们非常感谢您的支持
// 敬告：文件包含 DEVICE_I2C_PORT
// i2c通讯的初始化配置,需要调用device_i2c_init(),此处音频和其他设备共用端口，在audio_board_init()初始化，不需初始化
//     API规范: sevetest30_board_ctrl
//     外部函数应该调用board_status_get获取控制缓存变量,修改值后导入
///----注意：控制数据只有在完成sevetest30_board_ctrl工作之后，才会保存到board_ctrl_buf缓存中，如果果您只是外部定义了一个board_ctrl_t类型变量存储您的更改，
//     但是没有调用sevetest30_board_ctrl,board_ctrl_buf缓存数据将不会更新,而系统缓存的位置是board_ctrl_buf，而不是您自己定义的外部缓存，
///    意味着系统比如蓝牙读取，读到的数据将不是更新的数据，所以如果您要进行控制数据更改，务必保证sevetest30_board_ctrl工作进行了
///    如果只是单纯希望修改控制数据可以调用board_status_get直接获取系统缓存结构体指针进行修改，这样其他API读到数据将是更新的数据,但是只有sevetest30_board_ctrl被调用，硬件才会与控制数据同步
// github: https://github.com/701Enti


#include "board_ctrl.h"
#include "AGS10.h"
#include "AHT20.h"
#include "board.h"
#include "gt32l32s0140.h"
#include "OPT3001.h"
#include "MAX17048.h"

#include "HSCDTD008A.h"
#include "LSM6DS3TRC.h"
#include "driver/i2c_master.h"
#include "es8388.h"
#include "esp_log.h"
#include "esp_sleep.h"
#include "sevetest30_BWEDA.h"
#include "sevetest30_LedArray.h"
#include "sevetest30_gpio.h"
#include "sevetest30_touch.h"

static i2c_master_dev_handle_t amplifier_dev_handle = NULL;

esp_err_t board_ctrl_init_report[INIT_STEP_NUMBER] = {ESP_FAIL};

esp_periph_set_handle_t se30_periph_set_handle;

///----注意：控制数据只有在完成sevetest30_board_ctrl工作之后，才会保存到board_ctrl_buf缓存中，如果果您只是外部定义了一个board_ctrl_t类型变量存储您的更改，
//     但是没有调用sevetest30_board_ctrl,board_ctrl_buf缓存数据将不会更新,而系统缓存的位置是board_ctrl_buf，而不是您自己定义的外部缓存，
///    意味着系统比如蓝牙读取，读到的数据将不是更新的数据，所以如果您要进行控制数据更改，务必保证sevetest30_board_ctrl工作进行了
///    如果只是单纯希望修改控制数据可以调用board_status_get直接获取系统缓存结构体指针进行修改，这样其他API读到数据将是更新的数据,但是只有sevetest30_board_ctrl被调用，硬件才会与控制数据同步
board_ctrl_t *board_ctrl_buf = NULL;

esp_err_t amplifier_vol_dp_init();
esp_err_t amplifier_vol_dp_set(board_ctrl_t *board_ctrl);

void codechip_mode_and_status_set(board_ctrl_t *board_ctrl);
void codechip_volume_set(board_ctrl_t *board_ctrl);
void board_ctrl_buf_map(board_ctrl_t *board_ctrl,
                        board_ctrl_select_t ctrl_select);
void codec_set_mic_gain(board_ctrl_t *board_ctrl);
void codec_config_adc_input(board_ctrl_t *board_ctrl);
void codec_config_dac_output(board_ctrl_t *board_ctrl);

esp_err_t get_spi_pins_font_chip(
    spi_bus_config_t *spi_config,
    spi_device_interface_config_t *spi_device_interface_config);

esp_err_t get_spi_pins_ledarray(
    spi_bus_config_t *spi_config,
    spi_device_interface_config_t *spi_device_interface_config);

// API规范: sevetest30_board_ctrl :
// 外部函数应该调用board_status_get获取控制缓存变量,修改值后导入
/// @brief
/// 获取系统控制缓存结构体指针,应该使用获取的结构体指针，修改参数并以此调用sevetest30_board_ctrl()
/// @return 控制缓存结构体指针

/// @brief
/// 获取系统控制缓存结构体指针,应该使用获取的结构体指针，修改参数并以此调用sevetest30_board_ctrl()
/// @return 控制缓存结构体指针
board_ctrl_t *board_status_get() { return board_ctrl_buf; }

// /// @brief 初始化设备I2C总线
// /// @return ESP_OK: 成功
// /// @return ESP_ERR_NO_MEM: 内存不足
// /// @return ESP_ERR_NOT_FOUND: 未找到空闲总线
// esp_err_t device_i2c_init() {
//   const static char *TAG = "device_i2c_init";

//   i2c_master_bus_config_t bus_cfg = {
//       .i2c_port = DEVICE_I2C_PORT,
//       .sda_io_num = DEVICE_I2C_SDA_IO,
//       .scl_io_num = DEVICE_I2C_SCL_IO,
//       .clk_source = DEVICE_I2C_CLK_SRC,
//   };

//   i2c_master_bus_handle_t bus_handle;
//   esp_err_t ret = i2c_new_master_bus(&bus_cfg, &bus_handle);
//   if (ret != ESP_OK) {
//     ESP_LOGE(TAG, "I2C总线创建失败");
//     return ret;
//   }

//   ESP_LOGI(TAG, "初始化I2C总线完成");
//   return ESP_OK;
// }

/// @brief 全局设备初始化
/// @param board_ctrl 定义board_ctrl_t全局变量，进行所有值设置后导入
/// @return 初始化操作的所有esp_err_t返回记录
esp_err_t *sevetest30_all_device_init(board_ctrl_t *board_ctrl) {
  // // 初始化设备I2C总线(SEVETEST30的设备与音频共用I2C总线，所以无需执行)
  // device_i2c_init();

  // 初始化音频面板(包括了I2C的初始化和注册)
  audio_board_init();

  // LED阵列
  board_ctrl_init_report[LEDARRAY_INIT] = ledarray_init();

  // 字库芯片
  board_ctrl_init_report[FONTS_CHIP_INIT] = fonts_chip_init();

  // 初始化TCA6416A扩展IO芯片
  board_ctrl_init_report[TCA6416A_INIT] = TCA6416A_init();

  // 初始化GPIO服务(包括扩展GPIO)
  board_ctrl_init_report[SEVETEST30_GPIO_INIT] = sevetest30_gpio_init(
      board_ctrl->p_ext_io_mode, board_ctrl->p_ext_io_value);

  // 初始化音频功放音量数字电位器
  board_ctrl_init_report[AMP_VOL_DP_INIT] = amplifier_vol_dp_init();

  // AHT20(温湿度传感器)
  board_ctrl_init_report[AHT20_INIT] = AHT20_init();

  // AGS10(空气质量传感器)
  board_ctrl_init_report[AGS10_INIT] = AGS10_init();

  // OPT3001(环境光传感器)
  board_ctrl_init_report[OPT3001_INIT] = OPT3001_init();

  // MAX17048(电池状态传感器)
  board_ctrl_init_report[MAX17048_INIT] = MAX17048_init();

  // LSM6DS3TRC(姿态传感器)
  board_ctrl_init_report[LSM6DS3TRC_INIT] = LSM6DS3TRC_init();

  // HSCDTD008A(地磁场传感器)
  board_ctrl_init_report[HSCDTD008A_INIT] = HSCDTD008A_init();

  // 震动马达
  board_ctrl_init_report[VIBRA_MOTOR_INIT] =
      vibra_motor_init(VIBRA_IN1_IO, VIBRA_IN2_IO);

  // 全部初始化之后配置所有设备到指定模式
  board_ctrl_init_report[BOARD_CTRL_CONFIG] =
      sevetest30_board_ctrl(board_ctrl, BOARD_CTRL_ALL);

  return board_ctrl_init_report;
}

/// @brief 全局设备通过断电/失能/低功耗模式/深度睡眠使得设备进入软关机状态(硬件不支持除外)
void sevetest30_all_device_deep_sleep() {
  board_ctrl_t *board_ctrl = board_status_get();
  board_ctrl->p_ext_io_value->DISABLE_LED_BOARD = true;
  board_ctrl->p_ext_io_value->amplifier_MUTE = true;
  board_ctrl->p_ext_io_value->amplifier_SD = false;
  board_ctrl->p_ext_io_value->OTG_EN = false;
  sevetest30_board_ctrl(board_ctrl, BOARD_CTRL_ALL);

  vibra_motor_stop();
}

/// @brief
/// 立即执行关机,全局设备通过断电/失能/低功耗模式/深度睡眠使得设备进入软关机状态(硬件不支持除外)
void sevetest30_shutdown(void) {
  ESP_LOGW("main", "关机...");
  vTaskDelay(pdMS_TO_TICKS(3000));
  sevetest30_all_device_deep_sleep();
  esp_sleep_enable_ext0_wakeup(GPIO_NUM_1, 0);
  esp_deep_sleep_start();
}

/// @brief
/// 全局设备控制,外部函数应该调用board_status_get获取控制缓存变量,修改值后导入
/// @param board_ctrl
/// 调用board_status_get()获取系统控制缓存结构体，进行需要修改后放入
/// @param ctrl_select 选择控制的对象，这是一个枚举类型
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

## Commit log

2023-08-16 new file: .devcontainer/Dockerfile new file: .devcontainer/devcontainer.json new file: .gitignore new file: .vscode/c_cpp_properties.json new file: .vscode/extensions.json new file: .vscode/launch.js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
    [partitions.csv]
2024-01-28 Please enter the commit message for your changes. Lines starting with '#' will be ignored, and an empty message aborts the commit.
    On branch master
    Changes to be committed:
    modified: .vscode/c_cpp_properties.json
    modified: .vscode/settings.json
    modified: CMakeLists.txt
    deleted: components/701Enti/CMakeLists.txt
    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
2024-02-05 modified: .vscode/settings.json modified: components/sevetest30_board/board.c modified: components/sevetest30_board/board_ctrl.h modified: components/sevetest30_board/board_def.h modified: components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
2024-02-14 modified: .vscode/settings.json modified: components/sevetest30_board/CMakeLists.txt deleted: components/sevetest30_board/base64.h new file: components/sevetest30_board/base64_re.c new file: componen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
    [partitions.csv]
2024-02-16 modified: .vscode/settings.json modified: components/sevetest30_board/board_def.h modified: components/sevetest30_board/include/fonts_chip.h modified: components/sevetest30_board/include/sevetest30_B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
2024-02-19 modified: .vscode/settings.json modified: components/sevetest30_board/board_ctrl.h modified: components/sevetest30_board/board_def.h modified: components/sevetest30_board/include/TCA6416A.h modified: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
    [partitions.csv]
2024-02-21 modified: components/sevetest30_board/board_def.h modified: components/sevetest30_board/include/fonts_chip.h modified: main/fonts_chip.c modified: main/main.c modified: main/sevetest30_UI.c modified: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
2024-02-22 modified: .vscode/settings.json modified: components/sevetest30_board/base64_re.h modified: components/sevetest30_board/board_ctrl.h modified: components/sevetest30_board/board_def.h modified: main/N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
2024-02-22 modified: components/sevetest30_board/board_ctrl.h new file: components/sevetest30_board/include/BL5372.h modified: components/sevetest30_board/include/CMakeLists.txt modified: components/sevetest30_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
2024-02-23 modified: .vscode/settings.json modified: components/sevetest30_board/board_ctrl.h modified: components/sevetest30_board/board_def.h modified: components/sevetest30_board/board_pins_config.c modified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
2024-02-24 modified: components/sevetest30_board/board_def.h modified: components/sevetest30_board/include/BL5372.h modified: components/sevetest30_board/include/sevetest30_SWEDA.h modified: main/BL5372.c modif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
2024-03-03 modified: components/sevetest30_board/include/BL5372.h modified: components/sevetest30_board/include/CMakeLists.txt modified: components/sevetest30_board/include/lsm6ds3trc.h modified: components/sev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
2024-04-04 modified: .vscode/settings.json renamed: sevetest30.mp3 -> Fallacy.mp3 modified: components/sevetest30_board/include/fonts_chip.h modified: components/sevetest30_board/include/lsm6ds3trc.h modified: 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
2024-04-05 modified: components/sevetest30_board/board_def.h modified: components/sevetest30_board/include/lsm6ds3trc.h modified: components/sevetest30_board/include/sevetest30_SWEDA.h modified: main/board_ctrl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
2024-04-11 modified: .vscode/settings.json modified: Fallacy.mp3 modified: components/sevetest30_board/include/sevetest30_IWEDA.h modified: components/sevetest30_board/include/sevetest30_UI.h modified: componen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
2024-04-23 modified: .vscode/settings.json modified: components/sevetest30_board/include/sevetest30_IWEDA.h modified: components/sevetest30_board/include/sevetest30_UI.h modified: components/sevetest30_board/in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
    [partitions.csv]
2024-05-01 modified: .vscode/settings.json new file: components/sevetest30_board/include/AHT21.h modified: components/sevetest30_board/include/BL5372.h modified: components/sevetest30_board/include/CMakeLists.t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
2024-05-02 modified: components/sevetest30_board/board_def.h modified: components/sevetest30_board/include/AHT21.h modified: components/sevetest30_board/include/sevetest30_SWEDA.h modified: main/AHT21.c modifie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
2024-05-04 modified: .vscode/settings.json modified: components/sevetest30_board/board_ctrl.h modified: components/sevetest30_board/board_def.h new file: components/sevetest30_board/include/AGS10.h modified: co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
2024-05-04 modified: .vscode/settings.json modified: components/sevetest30_board/include/AGS10.h modified: components/sevetest30_board/include/CMakeLists.txt modified: components/sevetest30_board/include/sevete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
2024-05-05 modified: .vscode/settings.json modified: components/sevetest30_board/board_ctrl.h modified: components/sevetest30_board/include/sevetest30_IWEDA.h modified: components/sevetest30_board/include/sevet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
2024-06-04 modified: .vscode/settings.json modified: components/sevetest30_board/board_ctrl.h modified: components/sevetest30_board/include/CMakeLists.txt renamed: components/sevetest30_board/include/fonts_chip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
2025-04-05 正在修复已知问题,备份,准备由ESP-IDF4.4迁移到5.0
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2025-08-02 紧急修复
2025-08-03 紧急修复-工作流文件测试
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2025-08-14 删除不必要的managed_components目录并永久排除 修复和优化校准库 (#2)
    * 添加managed_components到.gitignore
    * 修复校准库LU求逆隐式转置问题 计算 XT * y使用第三方API 添加原地转置(存在API重命名)
    * 删除managed_components目录(类似build目录)以减少不必要占用
    1.managed_components目录类似build目录,构建时自动本地下载官方组件,Git追踪和云端存储是不必要的
    2.经检查,校准库LU求逆过程存在逆矩阵输出隐式转置问题,目前已经修复
    (校准库目前可能仍然存在一些问题,无法正确计算静态校准参数)
    3.数学工具库(包含普通版和fp64双精度版)最小二乘法中XT*y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
    [main.c]
2025-08-15 PR检查和文档同步工作流相关(含README更改) 添加.nokejyll (#3)
    注意: #2未更新个人分支，本次PR仅包含967174b至c5fa5a9 (下方相关提交)
    * 改用TruffleHog进行PR检查 更改README
    1.由于Gitleaks组织使用需要填写表单，我暂时无法访问它，改用TruffleHog，并更改相关README和注释
    * 修复DoxygenAutoDocSyncDoxygen
    2.发现文档同步调用复用工作流时有参数输入问题，这是之前job重命名build->prepare不完全导致，现已修复
    * 添加.nojekyll
    3.doxygen生成的文档资源含已“_”开头文件，因此添加.nokejyll空文件以禁止对它们的排除
2025-08-15 清理记录+工作流触发+GitHubPage云端访问体验相关 (#4)
    * 更改DoxygenAutoDocSyncDoxygen触发条件
    改为仅push和手动
    * 优化DoxygenAutoDocSyncDoxygen对文档子模块更新需求适配
    排除文档子模块相关推送的触发,防止文档仓库同步后,更新SEVETEST30仓库文档子模块时的push再次触发此工作流导致无限循环
    * 添加根目录index.html相关
    * 修复根目录index.html并改用script重定向优化本地离线访问
    添加和完善根目录index.html,使用script重定向,实现根路径跳转访问和友好本地离线访问体验(动态路径获取,无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
2025-08-16 尝试修复OfficialDocSubmoduleSync并测试(更改一些相关注释和文档) (#6)
    (正在测试工作流OfficialDocSubmoduleSync)
    1.发现OfficialDocSubmoduleSync未被触发,尝试改为监听DoxygenAutoDocSyncDoxygen而非可复用工作流
    2.删除不必要的branches字段
    3.更改相关注释和README内容
2025-08-16 Zeng jinlin newfeature (#7)
    * 优化变量引用空格问题并尝试修复OfficialDocSubmoduleSync.yml
    1.优化变量引用空格问题
    2.通过远程访问确定机器人分支是否存在
    3.改用如果存在机器人分支,删除后再推送同名分支的方案
    * 机器人分支名中添加文档子模块名便于区分
    4.机器人分支名改为OfficialDocRobot-{文档子模块名}-${本仓库相关代码分支名}
2025-08-16 文档同步方案更改+相关注释同步 (#8)
    * 尝试修复OfficialDocSubmoduleSync
    1.改用直接通过DoxygenAutoDocSyncDoxygen调用OfficialDocSubmoduleSync实现
    * 同步注释信息
    2.更改与文档同步相关的注释和README
2025-08-16 尝试修复和优化DoxygenAutoDocSyncDoxygen (#9)
    1.改为通过参数匹配工作流路径并指定分支名
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2025-08-17 Zeng jinlin newfeature (#12)
    * 添加if:always()未修复问题,因此删去
    发现OfficialDocSubmoduleSync第一个job的if字段在之前修改中遗漏删除,这可能是整个调用OfficialDocSubmoduleSync工作流job跳过的原因,尝试修复
    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
2025-08-17 修复检查机器人分支时URL遗漏owner问题并优化一些step结构 (#13)
    1.修复检查机器人分支时URL遗漏owner问题
    2.优化一些step结构
    3.添加了OfficialDocSubmoduleSync的输入参数owner,因此调用者DoxygenAutoDocSyncDoxygen需要添加它
2025-08-17 (解决#14分支操作问题)尝试修复和优化文档相关工作流 (#15)
    * 重新安装文档子模块DOC-SEVETEST30(master分支)到docs/official/repo_doc
    2.发现异常,重新安装子模块(指定分支名master)
    * DoxygenAutoDocSyncDoxygen重命名为DoxygenAutoDocSync+添加注意+尝试修复OfficialDocSubmoduleSync+更改相关注释和README
    1.使用简洁命名
    3.添加注意:SEVETEST30仓库是将每个文档仓库作为子模块独立管理的,子模块名必须与文档仓库名一致
    4.尝试修复OfficialDocSubmoduleSync子模块更新问题
2025-08-17 子模块安装路径错误,重新安装 (#16)
    子模块误安装到根目录,紧急修复
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2025-08-17 修复误添加的"}"问题 (#18)
    OfficialDocSubmoduleSync中修复误添加的"}"
2025-08-17 修复OfficialDocSubmoduleSync获取文档子模块短哈希异常 (#19)
    发现OfficialDocSubmoduleSync中获取文档子模块短哈希时子模块指定路径错误,修复异常
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2025-08-18 尝试修复OfficialDocSubmoduleSync子模块更新问题 (#25)
    * OfficialDocSubmoduleSync更新子模块前清理缓存和文件
    * 子模块更新添加--init
    更新前清理子模块缓存和文件,并在更新时指定--init
2025-08-18 OfficialDocSubmoduleSync修复和job命名优化 (#26)
    * 补充遗漏的机器人分支不存在情况的子模块更新策略
    1.之前的更改#25存在遗漏,机器人分支不存在与存在使用相同子模块更新策略,先清理缓存和文件,再更新模块,并指定--init
    * 重命名OfficialDocSubmoduleSync的 exists_false和exists_true
    2.job名exists_false重命名为robot_branch_exists_false
    3.job名exists_true重命名为robot_branch_exists_true
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2025-08-18 OfficialDocSubmoduleSync修复Extract context information中对机器人分支是否存在的检查问题 (#28)
    OfficialDocSubmoduleSync中的Extract context information在运行git ls-remote时的机器人分支名存在引用问题,引用了没有定义的变量ROBOT_UPDATE_BRANCH
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2025-08-18 修复和调试工作流 (#30)
    * 尝试修复TruffleHogPRCheck中不支持的args
    1.TruffleHogPRCheck改用args: "filesystem --directory=. --json"
    * 为了调试而暂时禁用PR创建
    2.OfficialDocSubmoduleSync暂时禁用PR创建
2025-08-18 修复和调试代码泄露检查和文档同步相关工作流 (#31)
    * 通过明确指定参数尝试修复TruffleHogPRCheck
    1.TruffleHogPRCheck直接通过with指定参数
    * OfficialDocSubmoduleSync恢复之前PR创建的暂时取消
    * 尝试通过推送后等待更长时间确保完成推送
    2.调试发现最终代码仓库推送正常,可能是等待时间过短
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2025-08-18 尝试修复和优化PR创建问题 (#35)
    * permissions添加checks: write
    1.OfficialDocSubmoduleSync和DoxygenAutoDocSync添加permissions - checks:write
    * Create PR时显式登录GitHub CLI
    2.OfficialDocSubmoduleSync创建PR时显式登录修复权限问题
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2025-08-18 TruffleHogPRCheck取消无效参数+尝试解决OfficialDocSubmoduleSync创建PR需要手动登录问题 (#38)
    * TruffleHogPRCheck取消无效参数
    * OfficialDocSubmoduleSync创建PR前登录时指定--hostname github.com
    * OfficialDocSubmoduleSync创建PR前确保gh最新
    尝试解决OfficialDocSubmoduleSync创建PR需要手动登录问题 (#38)
2025-08-18 OfficialDocSubmoduleSync添加条件执行修复文档子模块无更改导致的错误 (#39)
    推送代码仓库前检查是否存在更改并记录,如果无更改,不推送
    OfficialDocSubmoduleSync中步骤:Create PR和Wait for code repository push to complete
    添加条件执行修复文档子模块无更改导致的错误
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2025-08-18 修复对robot_branch_exists_false的gh更新配置遗漏+忽略gh请求本地凭证告警 (#43)
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2025-08-31 与校准库相关的数学库问题修复+缓存清理 (#49)
    * 修复一些与校准库相关的数学库中已知问题
    1.数学库最小二乘法相关实现已知问题修复
    * 清理Git对已加入.gitignore的managed_components目录残留缓存
    2.清理Git对需要忽略的目录的残留缓存,以停止所有追踪
    [main.c]
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2026-09-14 适配新的显示硬件+GPT对话功能+实现部分用户界面+可打印的3D实体外壳+PCB项目文件 (#52)
    * 更改LedArray库，以支持PT4硬件，当前处于测试阶段
    * 优化UI显示和FFT频谱支持+清理未使用的BL5372模块+字库支持x16尺寸字符+实时音频采集支持
    * 重构GPT交流模块+优化配置体验
    * refactor: 完成项目多维度优化与功能完善
    1. 新增Monocypher加密库组件支持
    2. 优化传感器、外设驱动逻辑
    3. 重构系统时间处理与UI界面逻辑
    4. 更新配置项与依赖管理
    5. 修正变量命名与代码可读性
    * 迁移到ESP-IDFv5.5.5+优化sevetest30_board配置+优化IWEDA句柄式调用支持(提供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
    [壳体.stl, 显示面板_2026-08-22.step, 显示驱动模块_2026-08-22.step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]
